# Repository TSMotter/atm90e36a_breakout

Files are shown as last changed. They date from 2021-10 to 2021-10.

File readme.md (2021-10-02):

Eagle project for a simples breakout board to test ATM90E36A IC.

### Notes:
- This circuit follows the schematic for the 3P4W circuit, present on application note *"Atmel-46104A-SE-M90E36A-ApplicationNote_043014"*.
- Components C22 through C29 are meant to be seen as a generic 0603. If you'll use the chip with Rogowsky coil, you should mount capacitors. If you'll use the chip with CT, you should mount resistors.
- This board served my needs but may need some modifications for your application. **Feel free to download and edit this as you wish.**

### PCB view:
- Top View:
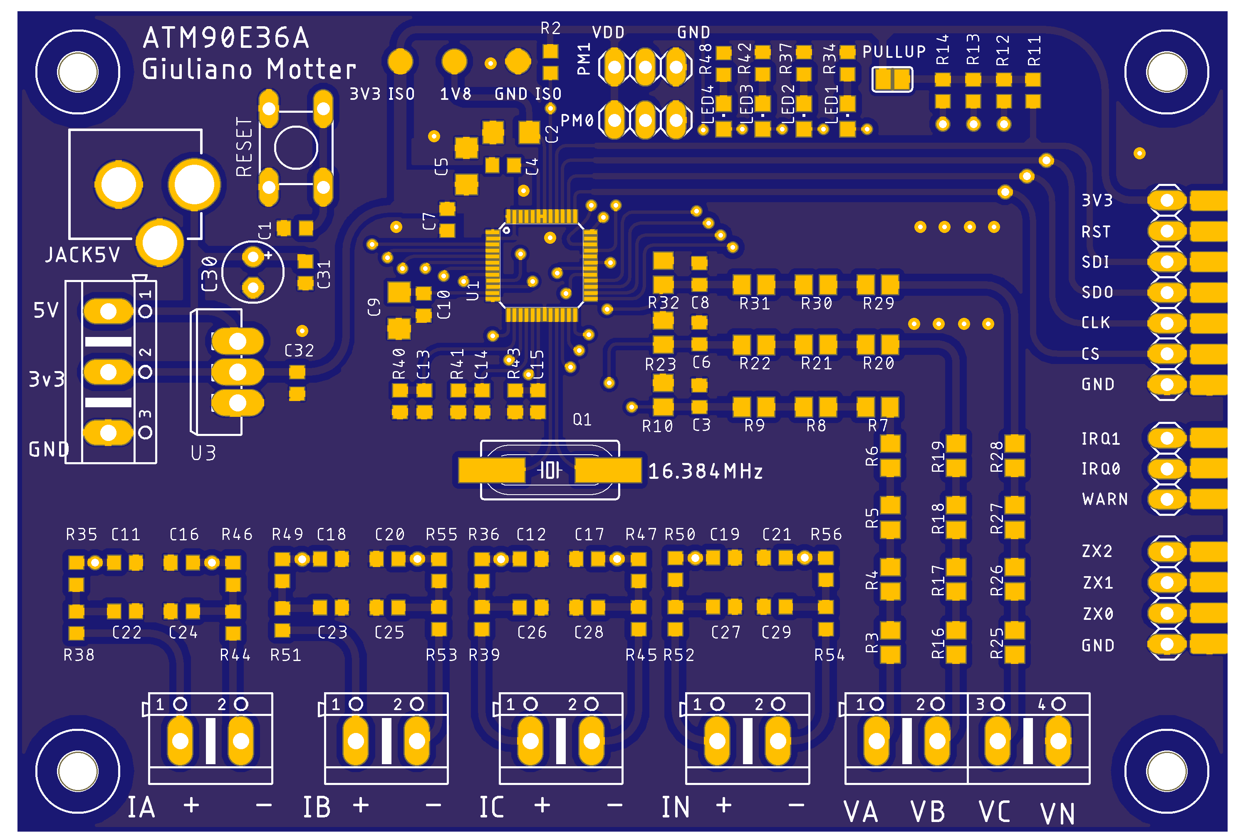
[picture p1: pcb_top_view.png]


- Botton View:
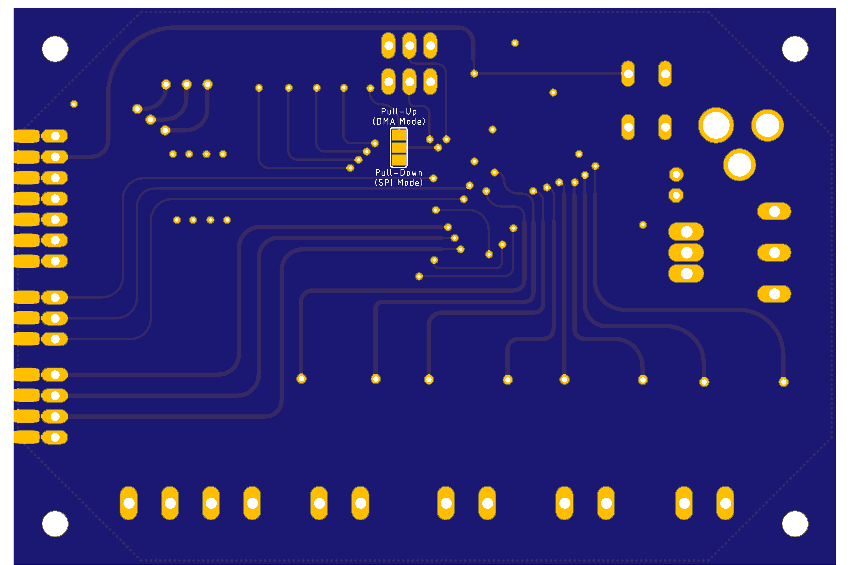
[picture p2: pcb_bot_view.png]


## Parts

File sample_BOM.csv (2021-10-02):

Qty | Value | Device | Package | Parts | Description | FABRICANTE | MF | MPN | OC_FARNELL | OC_NEWARK | PARTNUMBER | POPULARITY | SPICEPREFIX | TIPO | TP_SIGNAL_NAME
4 |  | AK500/2 | AK500/2 | IA, IB, IC, IN | CONNECTOR |  |  |  | unknown | unknown
1 |  | AK500/3 | AK500/3 | PWR | CONNECTOR |  |  |  | unknown | unknown
1 |  | AK500/4 | AK500/4 | V | CONNECTOR |  |  |  | unknown | unknown
1 |  | DCBARRELPTH | DCJACK_2MM_PTH | JACK5V | 2.0mm DC Barrel Jack
3 |  | PINHD-1X3 | 1X03 | PM0, PM1, PM2 | PIN HEADER
1 |  | PINHD-1X4 | 1X04 | JP4 | PIN HEADER
1 |  | PINHD-1X7 | 1X07 | JP1 | PIN HEADER
1 |  | SJ | SJ | PULLUP | SMD solder JUMPER
1 |  | SJ2W | SJ_2 | SJ1 | SMD solder JUMPER |  |  |  |  |  |  | 7
1 |  | TACTILE_SWITCHPTH | TACTILE_SWITCH_PTH | RESET | Chave Tactil-Switch | METALTEX |  |  |  |  | A06 |  |  | BOTAO
4 | 0603 | LEDCHIPLED_0805 | CHIPLED_0805 | LED1, LED2, LED3, LED4 | LED
6 | 100n 0603 | C0603 | 0603_IMPERIAL | C1, C4, C7, C10, C31, C32 | Capacitor cerâmico SMD (C0603) |  |  |  |  |  |  |  |  | CAPACITOR
5 | 10k 0603 | R0603 | 0603_IMPERIAL | R2, R11, R12, R13, R14 | Resistor SMD (R0603) |  |  |  |  |  |  |  |  | RESISTOR
3 | 10u 1206 | C1206 | 1206_IMPERIAL | C2, C5, C9 | Capacitor SMD (C1206) |  |  |  |  |  |  |  |  | CAPACITOR
1 | 16.384MHz | CRYSTALHC49UP | HC49UP | Q1 | CRYSTAL |  |  |  | unknown | unknown
8 | 18n - 2.4R 0603 | C0603 | 0603_IMPERIAL | C22, C23, C24, C25, C26, C27, C28, C29 | Capacitor cerâmico SMD (C0603) |  |  |  |  |  |  |  |  | CAPACITOR
14 | 18n 0603 | C0603 | 0603_IMPERIAL | C3, C6, C8, C11, C12, C13, C14, C15, C16, C17, C18, C19, C20, C21 | Capacitor cerâmico SMD (C0603) |  |  |  |  |  |  |  |  | CAPACITOR
8 | 1k - 0R 0603 | R0603 | 0603_IMPERIAL | R38, R39, R44, R45, R51, R52, R53, R54 | Resistor SMD (R0603) |  |  |  |  |  |  |  |  | RESISTOR
11 | 1k 0603 | R0603 | 0603_IMPERIAL | R35, R36, R40, R41, R43, R46, R47, R49, R50, R55, R56 | Resistor SMD (R0603) |  |  |  |  |  |  |  |  | RESISTOR
3 | 1k 0805 | R0805 | 0805_IMPERIAL | R10, R23, R32 | Resistor SMD R0805 |  |  |  |  |  |  |  |  | RESISTOR
1 | 2.2u | CPOL-EUE2.5-5 | E2,5-5 | C30 | POLARIZED CAPACITOR, European symbol |  |  |  |  |  |  |  | C
21 | 240k 0805 | R0805 | 0805_IMPERIAL | R3, R4, R5, R6, R7, R8, R9, R16, R17, R18, R19, R20, R21, R22, R25, R26, R27, R28, R29, R30, R31 | Resistor SMD R0805 |  |  |  |  |  |  |  |  | RESISTOR
4 | 510R 0603 | R0603 | 0603_IMPERIAL | R34, R37, R42, R48 | Resistor SMD (R0603) |  |  |  |  |  |  |  |  | RESISTOR
28 | EDGE | EDGE | EDGE | U$1, U$2, U$3, U$4, U$5, U$6, U$7, U$8, U$9, U$10, U$11, U$12, U$13, U$14, U$15, U$16, U$17, U$18, U$19, U$20, U$21, U$22, U$23, U$24, U$25, U$26, U$27, U$28
1 | LM1117-TO-220 | LM1117-TO-220 | TO-220 | U3
1 | M90E36A | M90E36A | TQFP-48 | U1 | Poly-Phase High-Performance Energy Metering IC (TQFP48) | ATMEL |  |  |  |  | ATM90E36A-AU-Y |  |  | CIRCUITO INTEGRADO
4 | MOUNT-HOLE3.0 | MOUNT-HOLE3.0 | 3,0 | H1, H2, H3, H4 | MOUNTING HOLE with drill center marker
3 | PTR1TP19R | PTR1TP19R | TP19R | 1V8, 3V3_ISO, GND_ISO | TEST PIN

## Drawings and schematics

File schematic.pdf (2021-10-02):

A

A

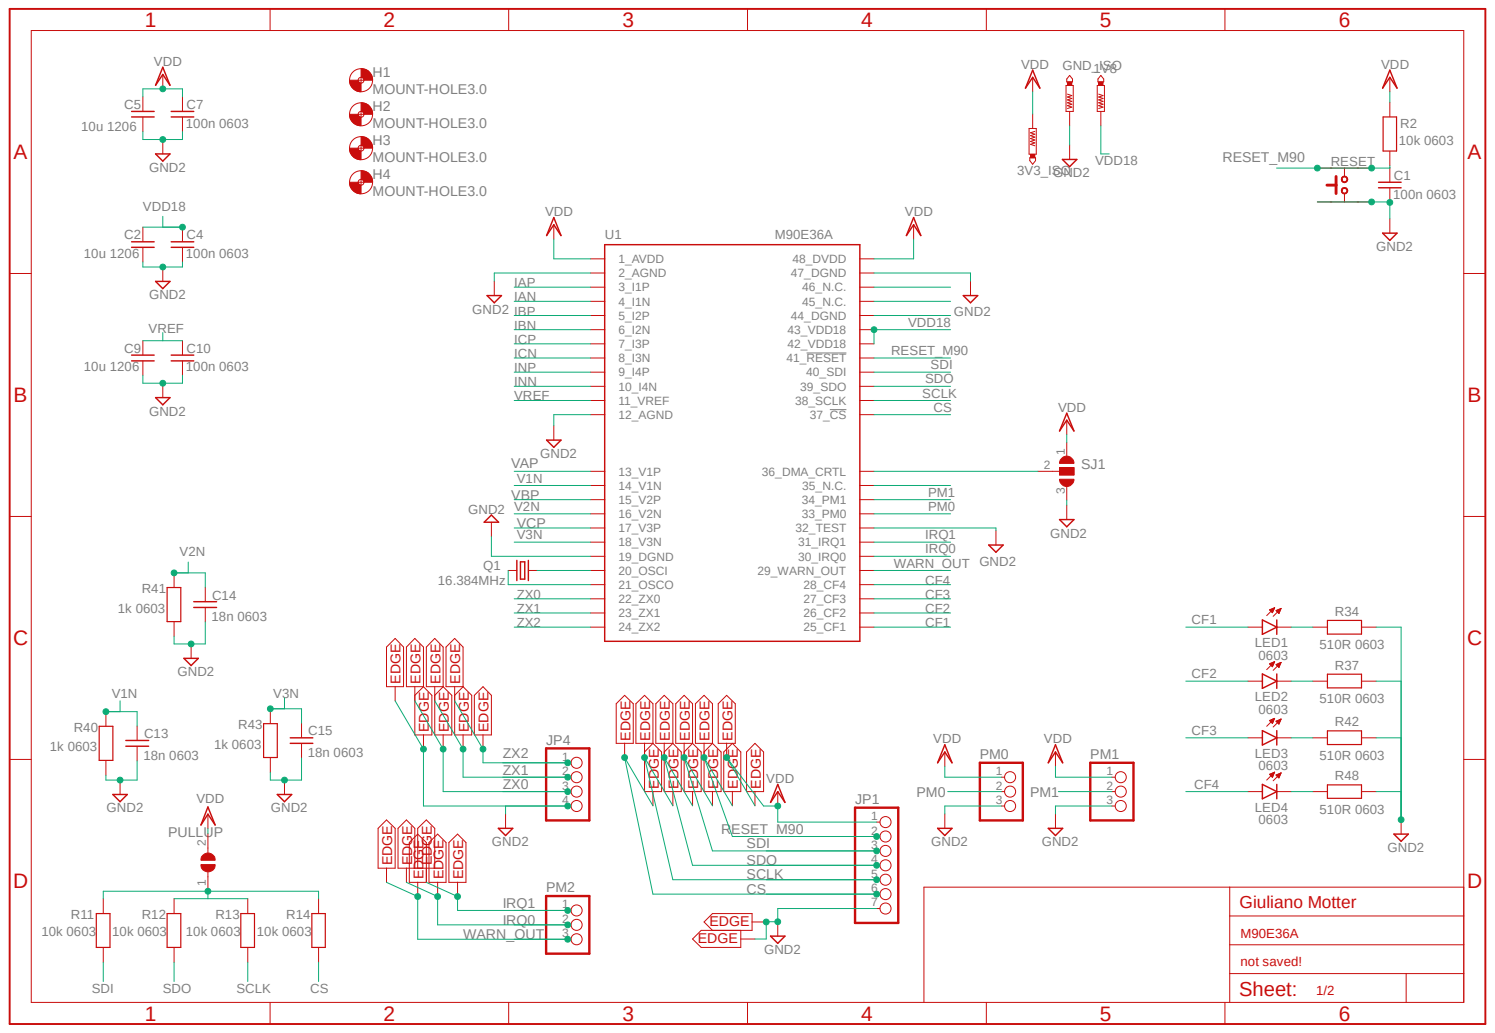
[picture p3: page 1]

A

A

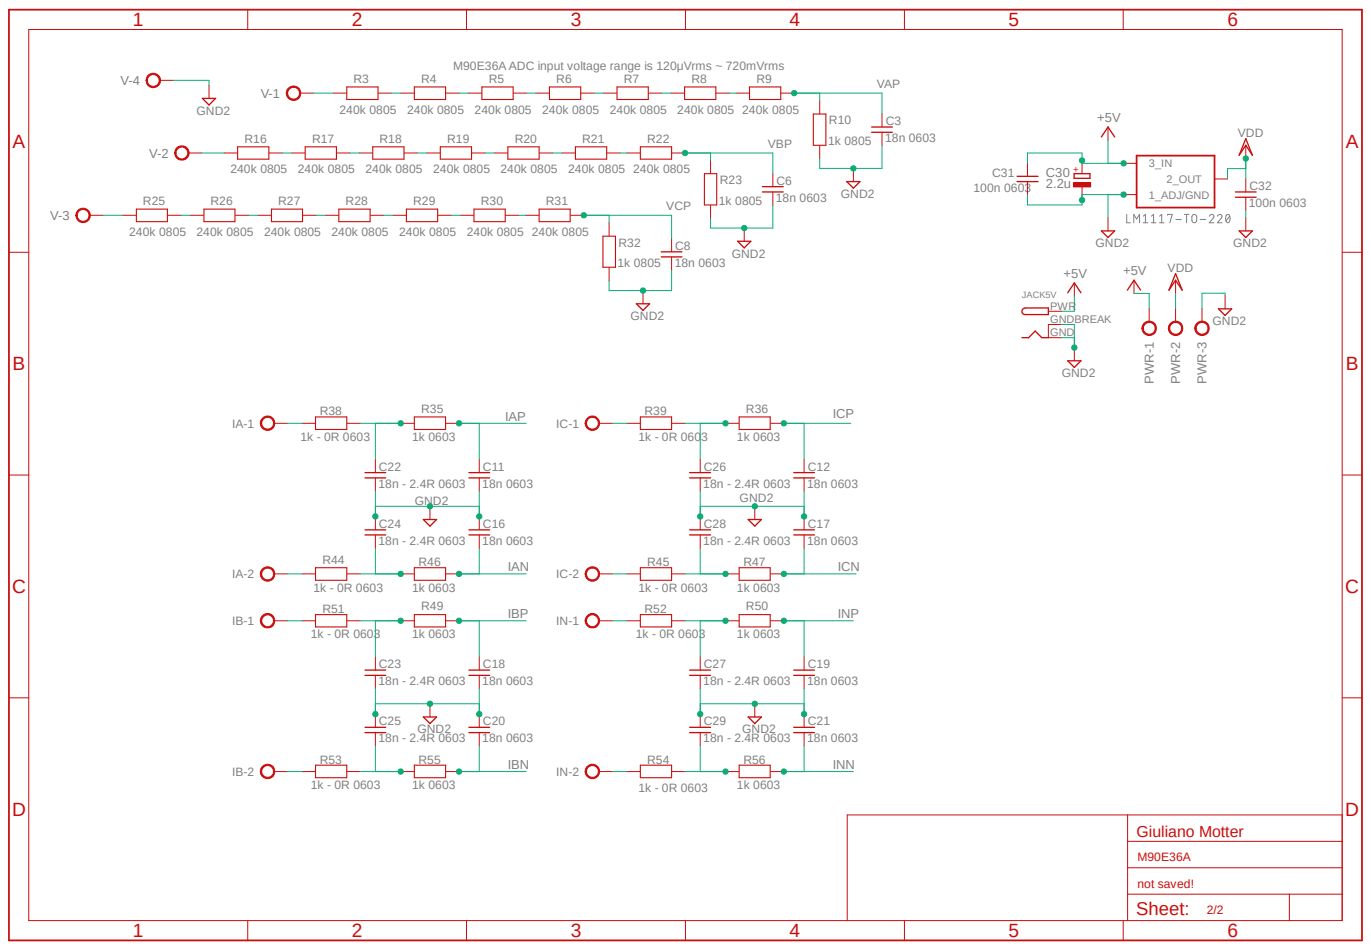
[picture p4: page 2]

M90E36A ADC input voltage range is 120μVrms ~ 720mVrms

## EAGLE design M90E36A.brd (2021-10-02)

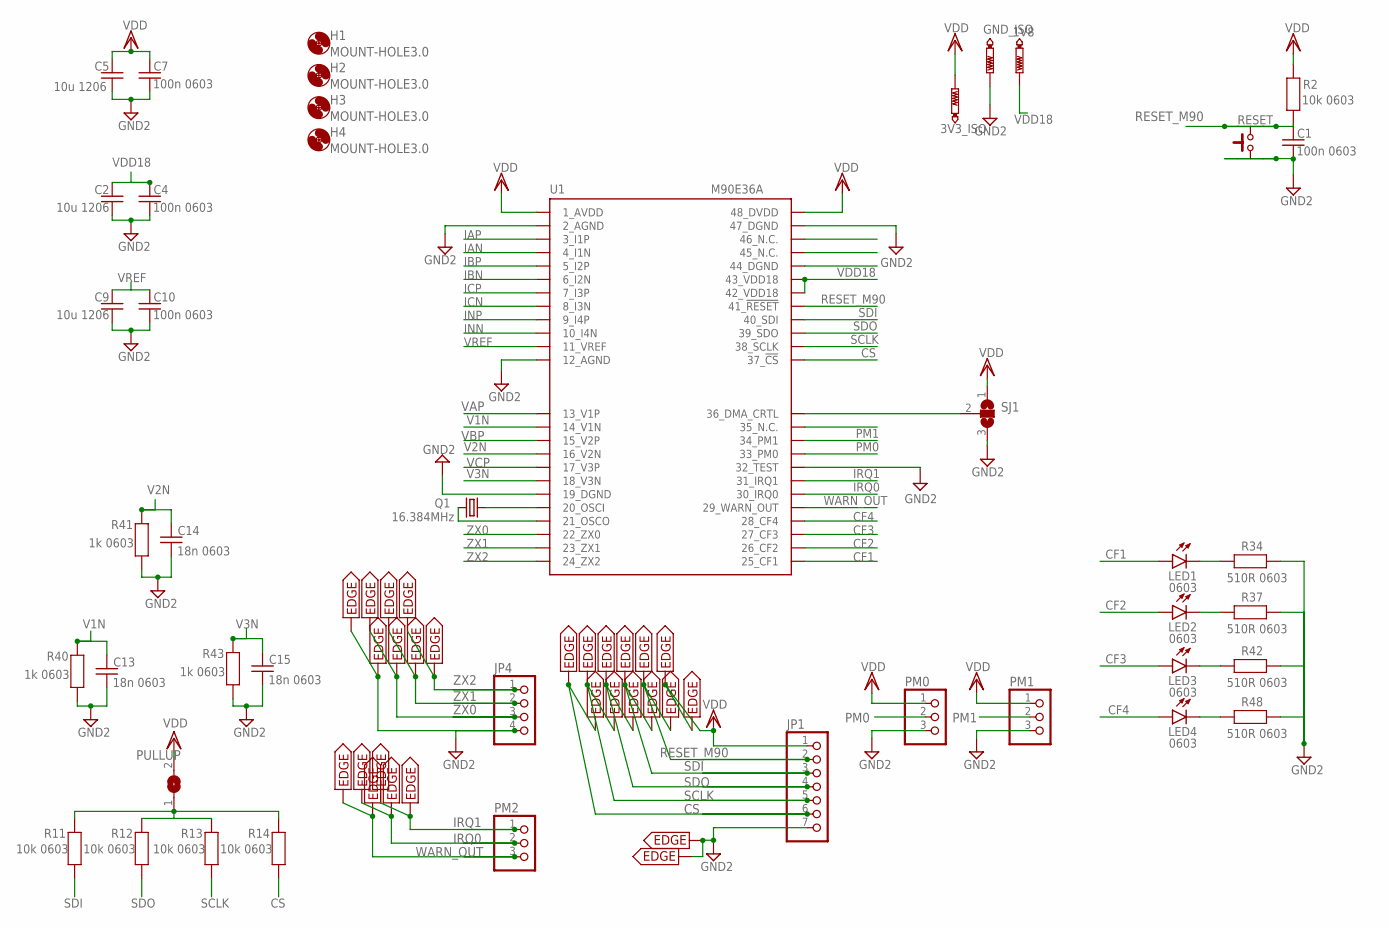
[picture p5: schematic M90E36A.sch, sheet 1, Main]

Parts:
1V8, 3V3_ISO: PTR1TP19R; TP19R
C1, C4, C7, C10: 100n 0603; 0603_IMPERIAL
C2, C5, C9: 10u 1206; 1206_IMPERIAL
C13, C14, C15: 18n 0603; 0603_IMPERIAL
GND_ISO: PTR1TP19R; TP19R
H1, H2, H3, H4: MOUNT-HOLE3.0; 3,0
JP1: PINHD-1X7; 1X07
JP4: PINHD-1X4; 1X04
LED1, LED2, LED3, LED4: 0603; CHIPLED_0805
PM0, PM1, PM2: PINHD-1X3; 1X03
PULLUP: SJ
Q1: 16.384MHz; HC49UP
R2, R11, R12, R13, R14: 10k 0603; 0603_IMPERIAL
R34, R37, R42, R48: 510R 0603; 0603_IMPERIAL
R40, R41, R43: 1k 0603; 0603_IMPERIAL
RESET: TACTILE_SWITCHPTH; TACTILE_SWITCH_PTH
SJ1: SJ2W; SJ_2
U1: M90E36A; TQFP-48
U$1, U$2, U$3, U$4, U$5, U$6, U$7, U$8, U$9, U$10, U$11, U$12, U$13, U$14, U$15, U$16, U$17, U$18, U$19, U$20, U$21, U$22, U$23, U$24, U$25, U$26, U$27, U$28: EDGE

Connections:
CF1: LED1.A, U1.P$25 (25_CF1)
CF2: LED2.A, U1.P$26 (26_CF2)
CF3: LED3.A, U1.P$27 (27_CF3)
CF4: LED4.A, U1.P$28 (28_CF4)
CS: JP1.6, R14.P$1, U1.P$37 (37_!CS), U$4.P$1, U$25.P$1
GND2: C1.P$1, C2.P$1, C4.P$1, C5.P$1, C7.P$1, C9.P$1, C10.P$1, C13.P$1, C14.P$1, C15.P$1, GND_ISO.TP, JP1.7, JP4.4, PM0.3, PM1.3, R34.P$2, R37.P$2, R40.P$1, R41.P$1, R42.P$2, R43.P$1, R48.P$2, RESET.P$1 (1), RESET.P$2 (2), SJ1.3, U1.P$2 (2_AGND), U1.P$12 (12_AGND), U1.P$19 (19_DGND), U1.P$32 (32_TEST), U1.P$47 (47_DGND), U$6.P$1, U$10.P$1, U$18.P$1, U$28.P$1; also elsewhere on the board
IAN: U1.P$4 (4_I1N); also elsewhere on the board
IAP: U1.P$3 (3_I1P); also elsewhere on the board
IBN: U1.P$6 (6_I2N); also elsewhere on the board
IBP: U1.P$5 (5_I2P); also elsewhere on the board
ICN: U1.P$8 (8_I3N); also elsewhere on the board
ICP: U1.P$7 (7_I3P); also elsewhere on the board
INN: U1.P$10 (10_I4N); also elsewhere on the board
INP: U1.P$9 (9_I4P); also elsewhere on the board
IRQ0: PM2.2, U1.P$30 (30_IRQ0), U$12.P$1, U$20.P$1
IRQ1: PM2.1, U1.P$31 (31_IRQ1), U$11.P$1, U$19.P$1
unnamed: LED1.C, R34.P$1
unnamed: LED2.C, R37.P$1
unnamed: LED3.C, R42.P$1
unnamed: LED4.C, R48.P$1
unnamed: Q1.2, U1.P$20 (20_OSCI)
unnamed: Q1.1, U1.P$21 (21_OSCO)
unnamed: PULLUP.1, R11.P$2, R12.P$2, R13.P$2, R14.P$2
unnamed: SJ1.2, U1.P$36 (36_DMA_CRTL)
PM0: PM0.2, U1.P$33 (33_PM0)
PM1: PM1.2, U1.P$34 (34_PM1)
RESET_M90: C1.P$2, JP1.2, R2.P$1, RESET.P$3 (3), RESET.P$4 (4), U1.P$41 (41_!RESET), U$14.P$1, U$27.P$1
SCLK: JP1.5, R13.P$1, U1.P$38 (38_SCLK), U$3.P$1, U$24.P$1
SDI: JP1.3, R11.P$1, U1.P$40 (40_SDI), U$1.P$1, U$22.P$1
SDO: JP1.4, R12.P$1, U1.P$39 (39_SDO), U$2.P$1, U$23.P$1
V1N: C13.P$2, R40.P$2, U1.P$14 (14_V1N)
V2N: C14.P$2, R41.P$2, U1.P$16 (16_V2N)
V3N: C15.P$2, R43.P$2, U1.P$18 (18_V3N)
VAP: U1.P$13 (13_V1P); also elsewhere on the board
VBP: U1.P$15 (15_V2P); also elsewhere on the board
VCP: U1.P$17 (17_V3P); also elsewhere on the board
VDD: 3V3_ISO.TP, C5.P$2, C7.P$2, JP1.1, PM0.1, PM1.1, PULLUP.2, R2.P$2, SJ1.1, U1.P$1 (1_AVDD), U1.P$48 (48_DVDD), U$5.P$1, U$26.P$1; also elsewhere on the board
VDD18: 1V8.TP, C2.P$2, C4.P$2, U1.P$42 (42_VDD18), U1.P$43 (43_VDD18)
VREF: C9.P$2, C10.P$2, U1.P$11 (11_VREF)
WARN_OUT: PM2.3, U1.P$29 (29_WARN_OUT), U$13.P$1, U$21.P$1
ZX0: JP4.3, U1.P$22 (22_ZX0), U$9.P$1, U$17.P$1
ZX1: JP4.2, U1.P$23 (23_ZX1), U$8.P$1, U$16.P$1
ZX2: JP4.1, U1.P$24 (24_ZX2), U$7.P$1, U$15.P$1

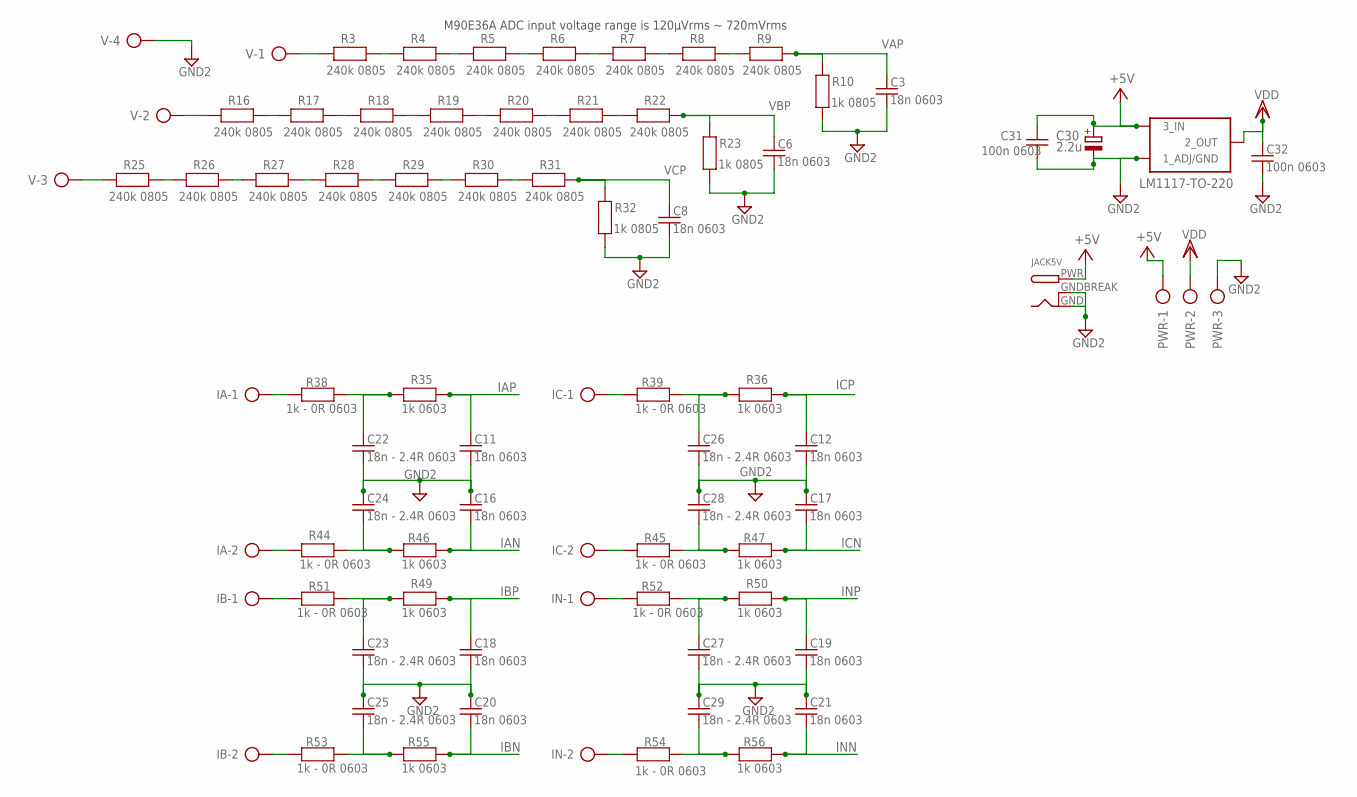
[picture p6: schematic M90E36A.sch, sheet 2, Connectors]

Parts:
C3, C6, C8, C11, C12, C16, C17, C18, C19, C20, C21: 18n 0603; 0603_IMPERIAL
C22, C23, C24, C25, C26, C27, C28, C29: 18n - 2.4R 0603; 0603_IMPERIAL
C30: 2.2u; E2,5-5
C31, C32: 100n 0603; 0603_IMPERIAL
IA: AK500/2
IB: AK500/2
IC: AK500/2
IN: AK500/2
JACK5V: DCBARRELPTH; DCJACK_2MM_PTH
PWR: AK500/3
R3, R4, R5, R6, R7, R8, R9, R16, R17, R18, R19, R20, R21, R22, R25, R26, R27, R28, R29, R30, R31: 240k 0805; 0805_IMPERIAL
R10, R23, R32: 1k 0805; 0805_IMPERIAL
R35, R36, R46, R47, R49, R50, R55, R56: 1k 0603; 0603_IMPERIAL
R38, R39, R44, R45, R51, R52, R53, R54: 1k - 0R 0603; 0603_IMPERIAL
U3: LM1117-TO-220; TO-220
V: AK500/4

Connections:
+5V: C30.+, C31.P$2, JACK5V.PWR, PWR.1, U3.3 (3_IN)
GND2: C3.P$1, C6.P$1, C8.P$1, C11.P$1, C12.P$1, C16.P$2, C17.P$2, C18.P$1, C19.P$1, C20.P$2, C21.P$2, C22.P$1, C23.P$1, C24.P$2, C25.P$2, C26.P$1, C27.P$1, C28.P$2, C29.P$2, C30.-, C31.P$1, C32.P$1, JACK5V.GND, JACK5V.GNDBREAK, PWR.3, R10.P$1, R23.P$1, R32.P$1, U3.1 (1_ADJ/GND), V.4; also elsewhere on the board
IAN: C16.P$1, R46.P$2; also elsewhere on the board
IAP: C11.P$2, R35.P$2; also elsewhere on the board
IBN: C20.P$1, R55.P$2; also elsewhere on the board
IBP: C18.P$2, R49.P$2; also elsewhere on the board
ICN: C17.P$1, R47.P$2; also elsewhere on the board
ICP: C12.P$2, R36.P$2; also elsewhere on the board
INN: C21.P$1, R56.P$2; also elsewhere on the board
INP: C19.P$2, R50.P$2; also elsewhere on the board
unnamed: R3.P$2, R4.P$1
unnamed: R4.P$2, R5.P$1
unnamed: R5.P$2, R6.P$1
unnamed: R6.P$2, R7.P$1
unnamed: R7.P$2, R8.P$1
unnamed: R8.P$2, R9.P$1
unnamed: R3.P$1, V.1
unnamed: R16.P$2, R17.P$1
unnamed: R17.P$2, R18.P$1
unnamed: R18.P$2, R19.P$1
unnamed: R19.P$2, R20.P$1
unnamed: R20.P$2, R21.P$1
unnamed: R21.P$2, R22.P$1
unnamed: R25.P$2, R26.P$1
unnamed: R26.P$2, R27.P$1
unnamed: R27.P$2, R28.P$1
unnamed: R28.P$2, R29.P$1
unnamed: R29.P$2, R30.P$1
unnamed: R30.P$2, R31.P$1
unnamed: R16.P$1, V.2
unnamed: R25.P$1, V.3
unnamed: IA.2, R44.P$1
unnamed: C24.P$1, R44.P$2, R46.P$1
unnamed: IC.1, R39.P$1
unnamed: C26.P$2, R36.P$1, R39.P$2
unnamed: IA.1, R38.P$2
unnamed: C22.P$2, R35.P$1, R38.P$1
unnamed: IC.2, R45.P$2
unnamed: C28.P$1, R45.P$1, R47.P$1
unnamed: IB.1, R51.P$2
unnamed: C23.P$2, R49.P$1, R51.P$1
unnamed: IB.2, R53.P$2
unnamed: C25.P$1, R53.P$1, R55.P$1
unnamed: IN.1, R52.P$2
unnamed: C27.P$2, R50.P$1, R52.P$1
unnamed: IN.2, R54.P$2
unnamed: C29.P$1, R54.P$1, R56.P$1
VAP: C3.P$2, R9.P$2, R10.P$2; also elsewhere on the board
VBP: C6.P$2, R22.P$2, R23.P$2; also elsewhere on the board
VCP: C8.P$2, R31.P$2, R32.P$2; also elsewhere on the board
VDD: C32.P$2, PWR.2, U3.2 (2_OUT); also elsewhere on the board

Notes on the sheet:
M90E36A ADC input voltage range is 120μVrms ~ 720mVrms

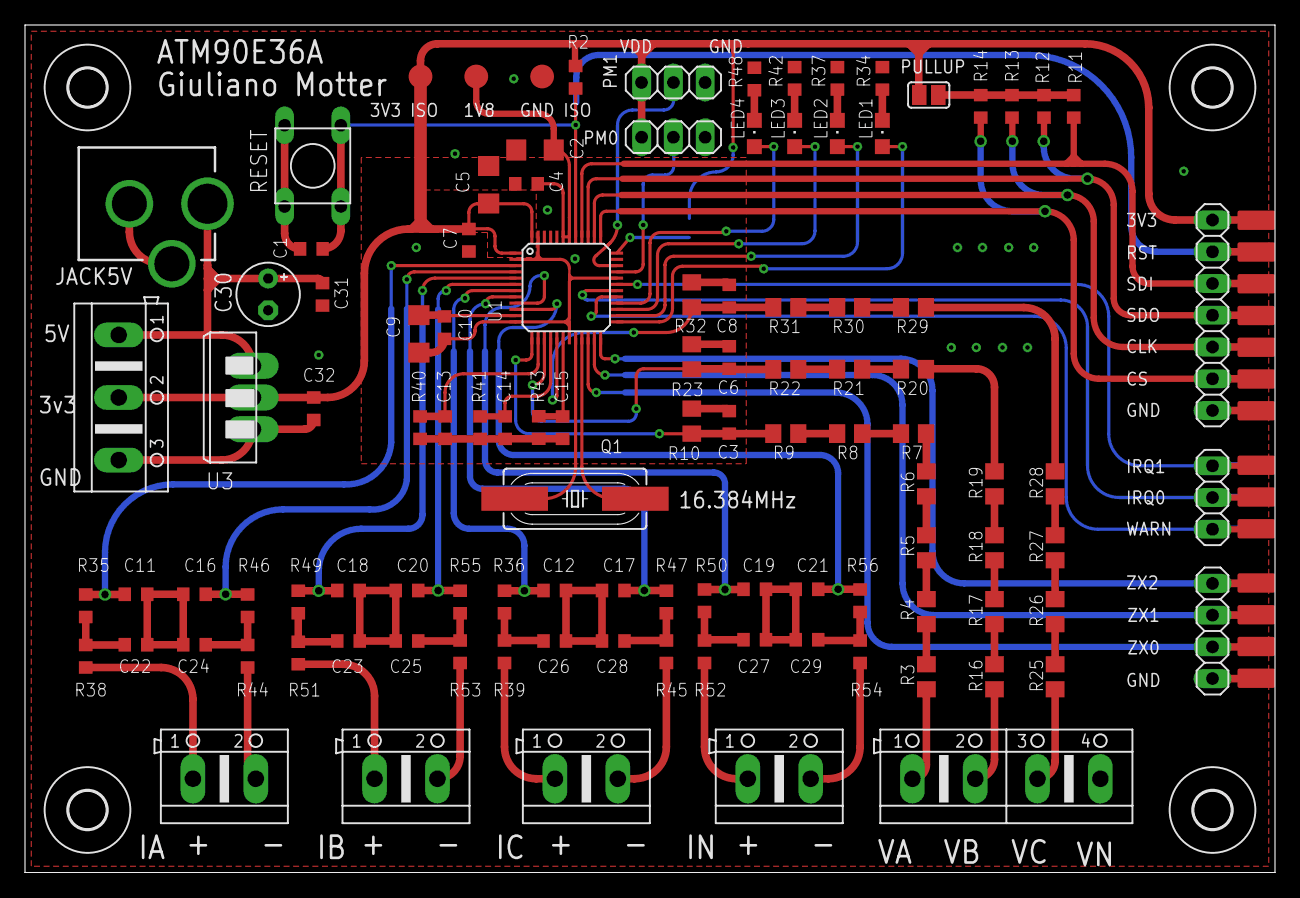
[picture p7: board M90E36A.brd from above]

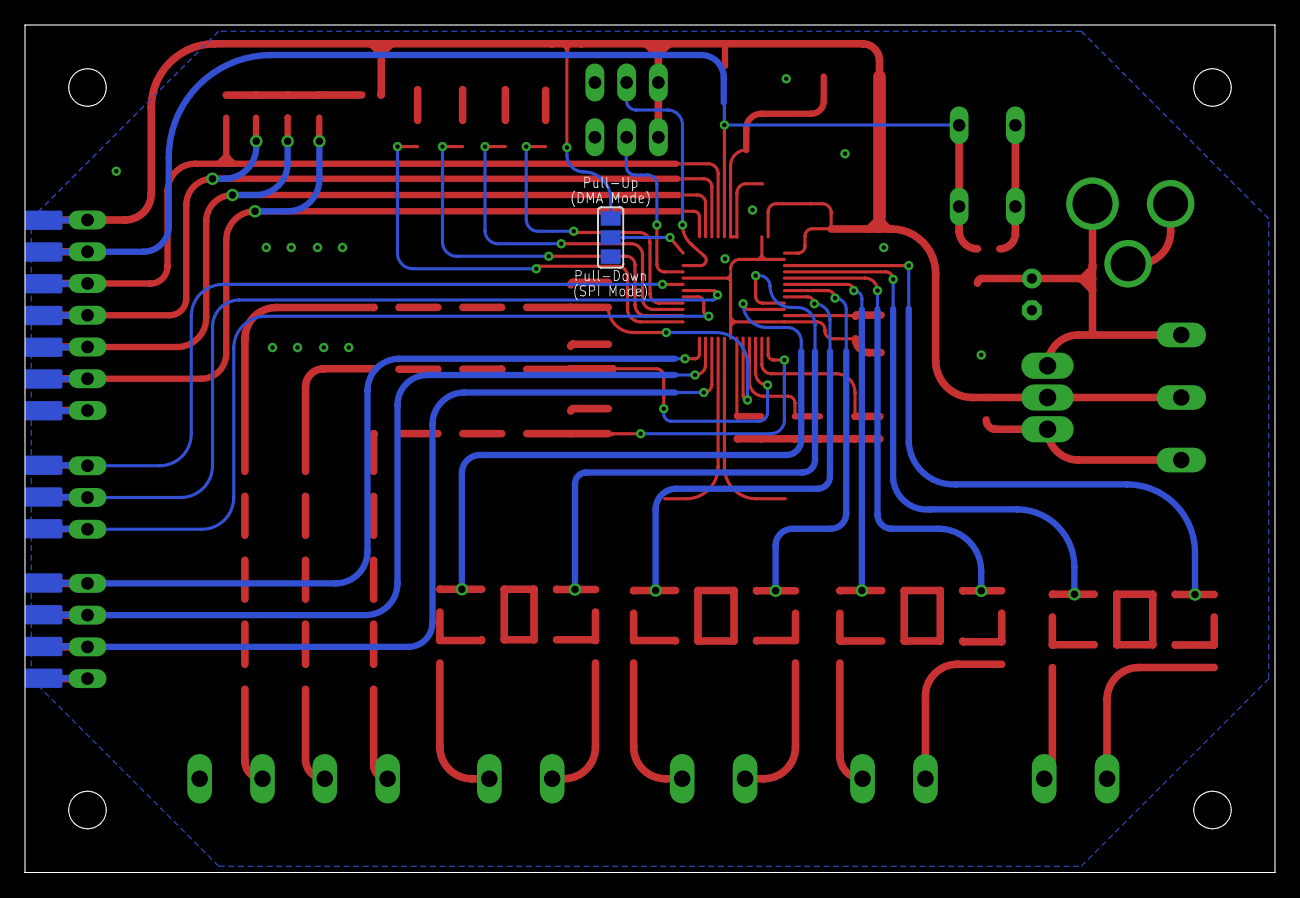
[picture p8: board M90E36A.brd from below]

Board: 2 copper layers, 100.0 x 67.8 mm, 141 parts (15 on the bottom side), 81 nets.
